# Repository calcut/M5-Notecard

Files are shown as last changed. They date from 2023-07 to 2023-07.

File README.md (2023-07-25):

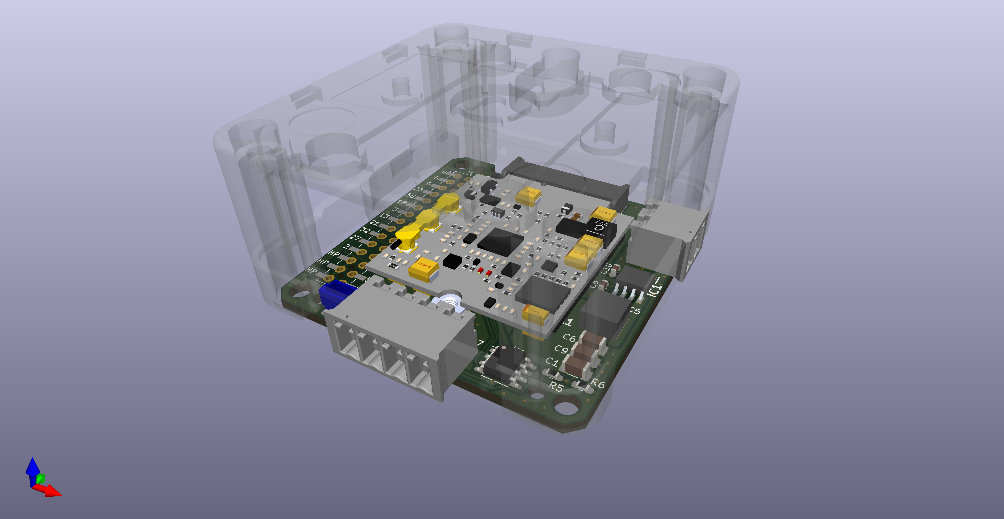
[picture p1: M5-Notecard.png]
3D Image


A KiCAD project for a PCB to interface a Blues Wireless Notecard to M5 Stack Core2
Should also work with CoreS3

Intended to fit into a [M5 Base26](https://shop.m5stack.com/products/base26-proto-industrial-board-module-v1-1)

Features Include
- Enables "Outboard DFU", from Notecard to ESP32
- RS485 interface for industrial modbus connections
- 12/24V to 5V buck regulator

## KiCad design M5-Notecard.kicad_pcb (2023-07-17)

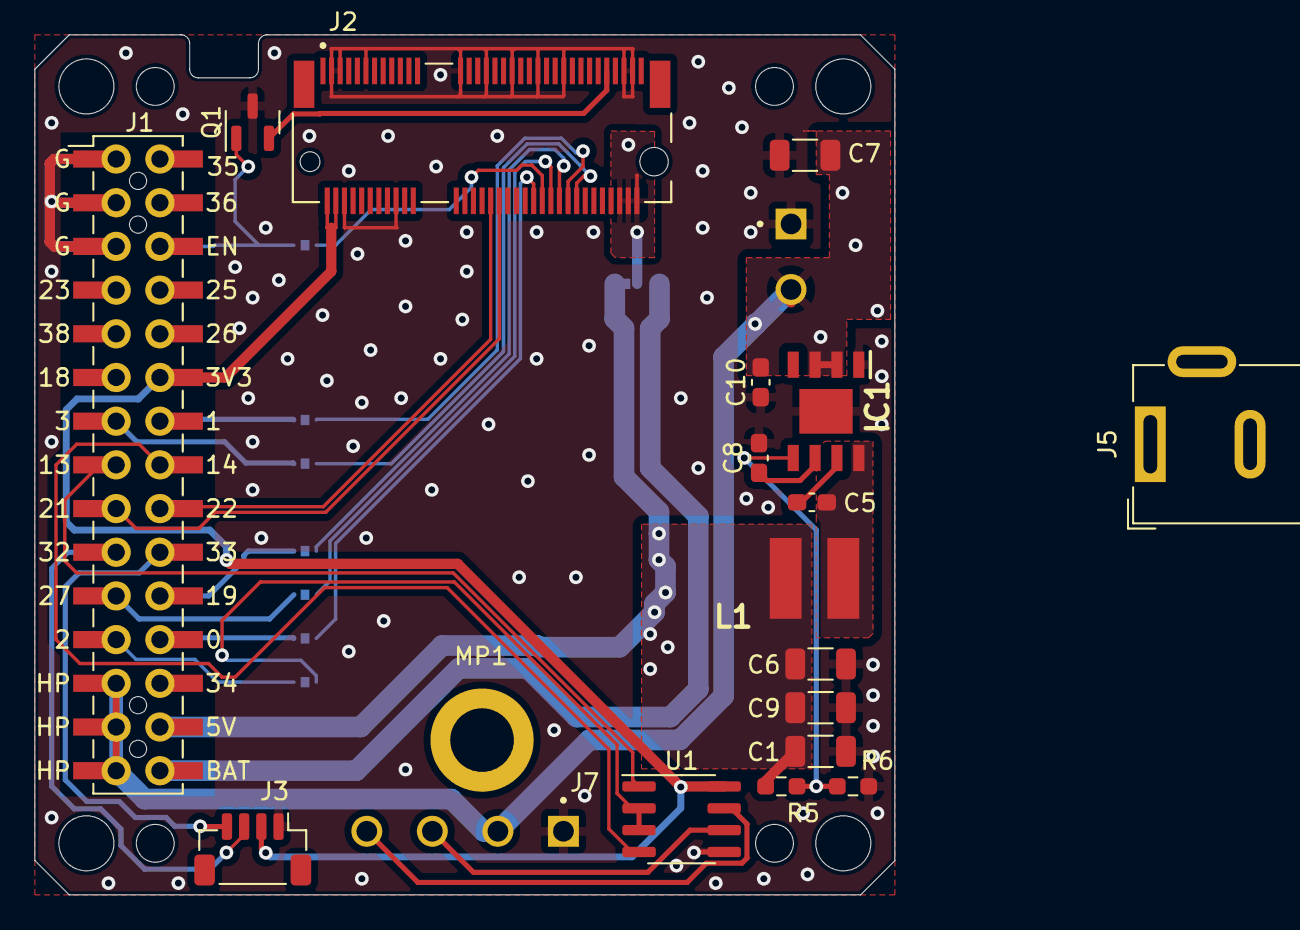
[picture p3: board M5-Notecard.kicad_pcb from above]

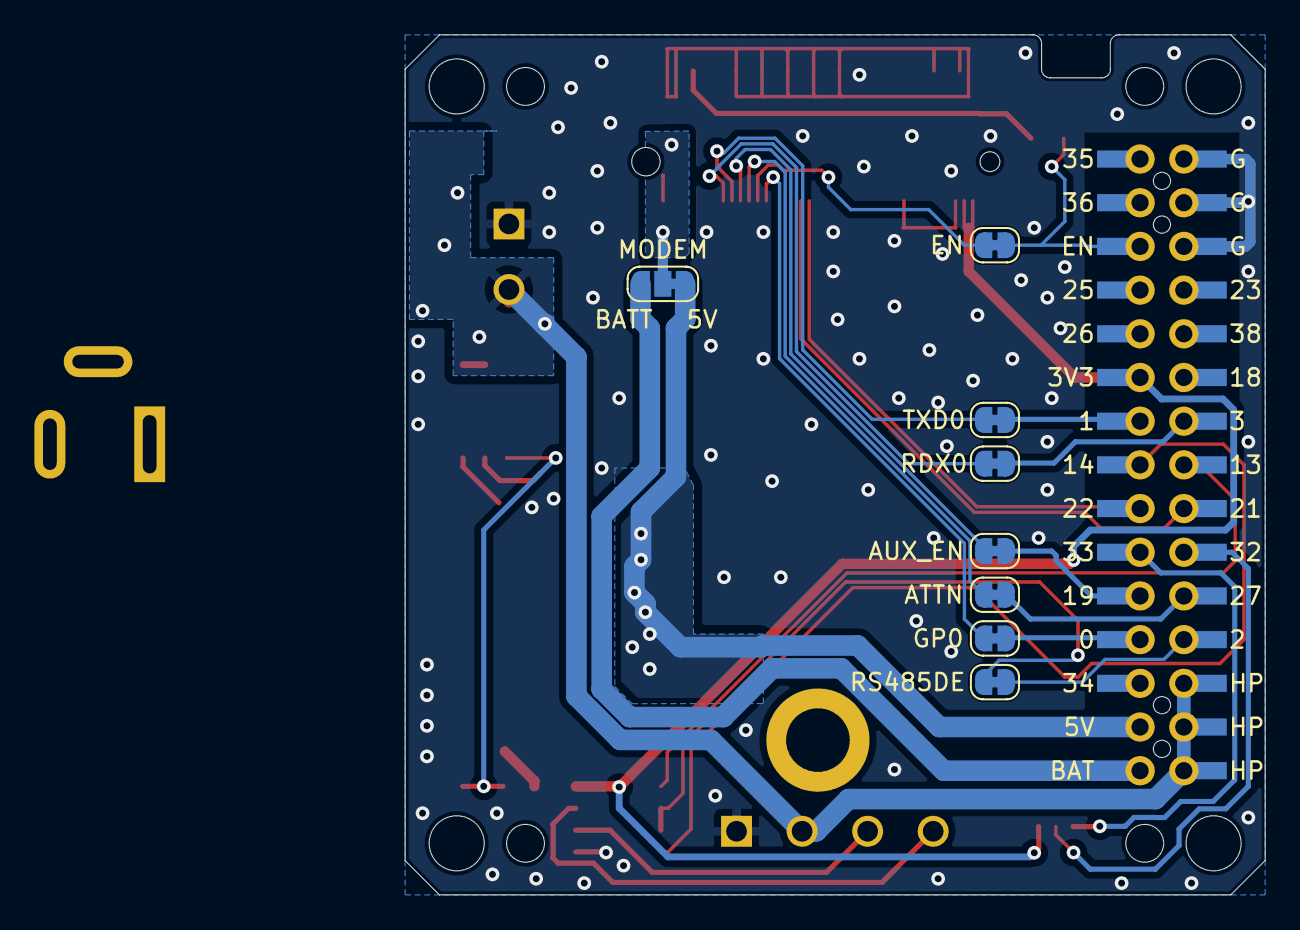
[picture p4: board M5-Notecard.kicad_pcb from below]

Board: 2 copper layers, 50.0 x 50.0 mm, 36 parts (8 on the bottom side), 33 nets.

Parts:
C1, C6, C7, C9: 22uF; C_1206_3216Metric
C5: 0.1uF; C_0603_1608Metric_Pad1.08x0.95mm_HandSolder
C8: 1uF; C_0603_1608Metric_Pad1.08x0.95mm_HandSolder
C10: 220nF; C_0603_1608Metric_Pad1.08x0.95mm_HandSolder
H1, H2, H3, H4: MountingHole; BF@MountingHole_3.2mm_M3
H5, H6, H7, H8: MountingHole; BF@MountingHole_2.2mm_M2
IC1: LMR33630CDDAR; SOIC127P600X170-9N
J1: M-BUS; BF@M5Stack_MBUS_CORE2
J2: Bus_M.2_Socket_E; AMPHENOL_MDT420E01001_Notecard
J3: 110990030; JST_SH_BM04B-SRSS-TB_1x04-1MP_P1.00mm_Vertical
J5: Barrel_Jack; BarrelJack_Wuerth_6941xx301002
J6: 284513-2; TE_284513-2
J7: 284513-4; TE_284513-4
JP1, JP2, JP3, JP4, JP6, JP7, JP8: SolderJumper_2_Bridged; SolderJumper-2_P1.3mm_Bridged_RoundedPad1.0x1.5mm
JP5: SolderJumper_3_Bridged12; SolderJumper-3_P1.3mm_Bridged12_RoundedPad1.0x1.5mm_NumberL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
L1: XAL5030-601MEB; Coilcraft_50xx-40xx_hybrid
MP1: 9774025151R; WE_9774025151R
Q1: BC856; SOT-23
R5: 100K; R_0603_1608Metric_Pad0.98x0.95mm_HandSolder
R6: 24.9K; R_0603_1608Metric_Pad0.98x0.95mm_HandSolder
U1: SP3481EN; SOIC-8_3.9x4.9mm_P1.27mm

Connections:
+3V3: J1.11, J2.2 (VIO_P), J2.4 (VIO_P), J3.2, U1.8 (VCC)
+5V: C1.1, C6.1, C9.1, J1.27, JP5.1 (A), L1.2, R5.1
+12V: C7.1, C10.2, IC1.2 (VIN), IC1.3 (EN), J1.26, J1.28, J1.30, J6.2, J7.2
+BATT: J1.29, JP5.3 (B)
/ATTN: J1.22, JP2.1 (A)
/AUX_EN: J1.21, JP4.1 (A)
/BOOT: C5.1, IC1.7 (BOOT)
/EN: J1.5, JP7.1 (A), Q1.1 (B)
/FB: IC1.5 (FB), R5.2, R6.1
/GPIO0: J1.23, JP6.1 (A)
/RS485_A: J7.3, U1.6 (A)
/RS485_B: J7.4, U1.7 (B)
/RS485_DE: J1.24, JP8.1 (A)
/RXD0: J1.14, JP1.1 (A)
/RXD2: J1.16, U1.1 (RO)
/SW: C5.2, IC1.8 (SW), L1.1
/TXD0: J1.13, JP3.1 (A)
/TXD2: J1.15, U1.4 (DI)
/VCC: C8.2, IC1.6 (VCC)
/VMODEM: J2.70 (VMODEM_P), J2.72 (VMODEM_P), J2.74 (VMODEM_P), JP5.2 (C)
/extSCL: J1.19, J3.4
/extSDA: J1.20, J3.3
/intSCL: J1.17, J2.40 (SCL_P)
/intSDA: J1.18, J2.42 (SDA_P)
GND: C1.2, C6.2, C7.2, C8.1, C9.2, C10.1, IC1.1 (PGND), IC1.9 (AGND), J1.2, J1.4, J1.6, J2.3 (GND), J2.5 (GND), J2.6 (GND), J2.11 (GND), J2.18 (GND), J2.33 (GND), J2.39 (GND), J2.45 (GND), J2.51 (GND), J2.57 (GND), J2.71 (GND), J2.73 (GND), J3.1, J6.1, J7.1, Q1.3 (C), R6.2, U1.5 (GND)
unnamed: J2.54 (ATTN_P), JP2.2 (B)
unnamed: J2.50 (AUX3), JP6.2 (B)
unnamed: J2.52 (AUX4), JP7.2 (B)
unnamed: J2.56 (AUX_EN_P), JP4.2 (B)
unnamed: J2.58 (AUX_RX_P), JP3.2 (B)
unnamed: J2.60 (AUX_TX_P), JP1.2 (B)
unnamed: J2.67 (NRST), Q1.2 (E)
unnamed: JP8.2 (B), U1.2 (~RE), U1.3 (DE)

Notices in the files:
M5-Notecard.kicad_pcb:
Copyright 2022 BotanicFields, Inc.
